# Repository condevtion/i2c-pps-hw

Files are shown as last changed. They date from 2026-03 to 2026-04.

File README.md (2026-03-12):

# Schematics for Programmable DC-DC Power Supply with I2C Interface

## About

The repository contains a schematic for the Programmable Power Supply.

## Specifications
- Controller: Texas Instruments [BQ25758S](https://www.ti.com/product/BQ25758S)
- Input voltage: 5V (4-6V - hardware power good window)
- Input current: up to 5A (hardware limited)
- Output voltage: programmable by I2C in controller defined range (3.3 - 26V)
- Output current: up to 5A (hardware limited)
- Switching frequency: 250kHz

## Schematics Structure
The device is complex enough for the schematics to be split into several pages, one for each functional block.
- Controller and Power Stage - consists of the BQ25758S controller, the power MOSFETs, and the inductor
- Input Filter and Sensor - a set of input capacitors and the input current sense resistor connected according to 4-point probes (Kelvin) method
- Output Filter and Sensor - the same for output circuit
- Master Switch - an input protection and an electronically controllable power switch
- Digital I/O and Indication - digital interface between controller and I2C host, contains as well a status LED, a power good LED, and an independent voltage regulator for the digital circuit
- Programming - a set of resistors to define controller's operating mode and HW limits for voltage and current
For now the pages contain mainly just network and hierarchical labels.

## Major Networks and Busses
- **`+5V_Prot`** - protected positive input voltage. The master switch page contains an input connector and protection circuit (fuse, TVS diode, polarity protection) after which the network starts. It is used as well to power the digital I/O and indication block
- **`+5V_Run`** - positive input voltage after the master switch itself (goes to the input filter and powers the controller). It is live while **`EN`** pin high
- **`EN`** - master switch control signal (should be high to turn the switch on and low to turn it OFF)
- **`+5V_Filtered`** - output of the input filter
- **`VOUT`** - the output voltages bus (contains power stage output and whole device output networks, goes to the output filter)
- **`I2C`** - I2C bus itself (connected to `SCL` and `SDA` pins)
- **`GPIO`** - groups digital I/O lines: interrupt, power good, status, and chip enable
- **`PROG`** - groups the rest of analog input lines which should be connected to the programming block to set operating mode and limits for the controller

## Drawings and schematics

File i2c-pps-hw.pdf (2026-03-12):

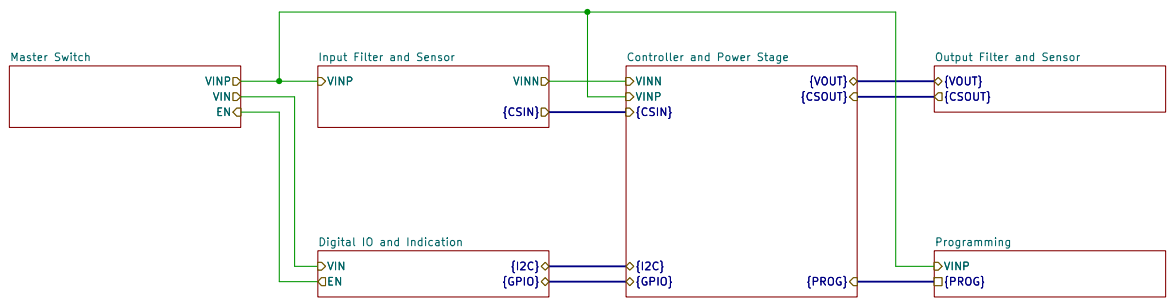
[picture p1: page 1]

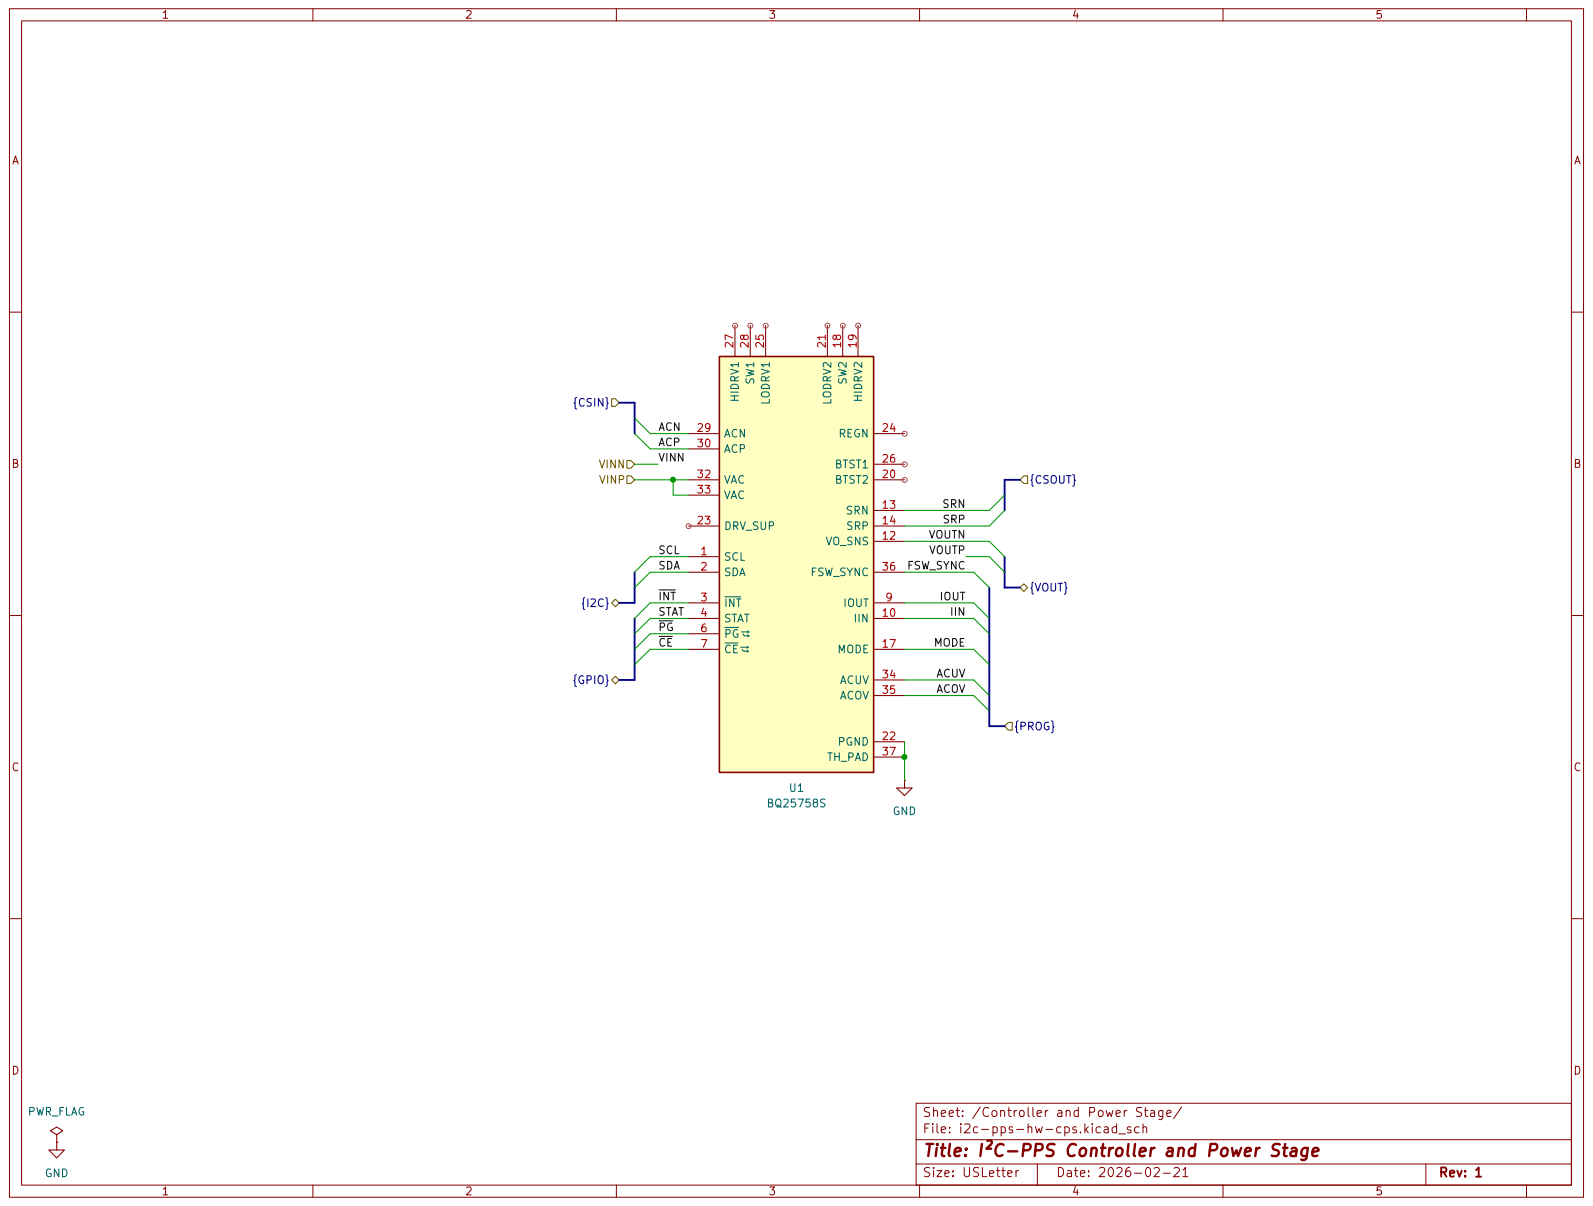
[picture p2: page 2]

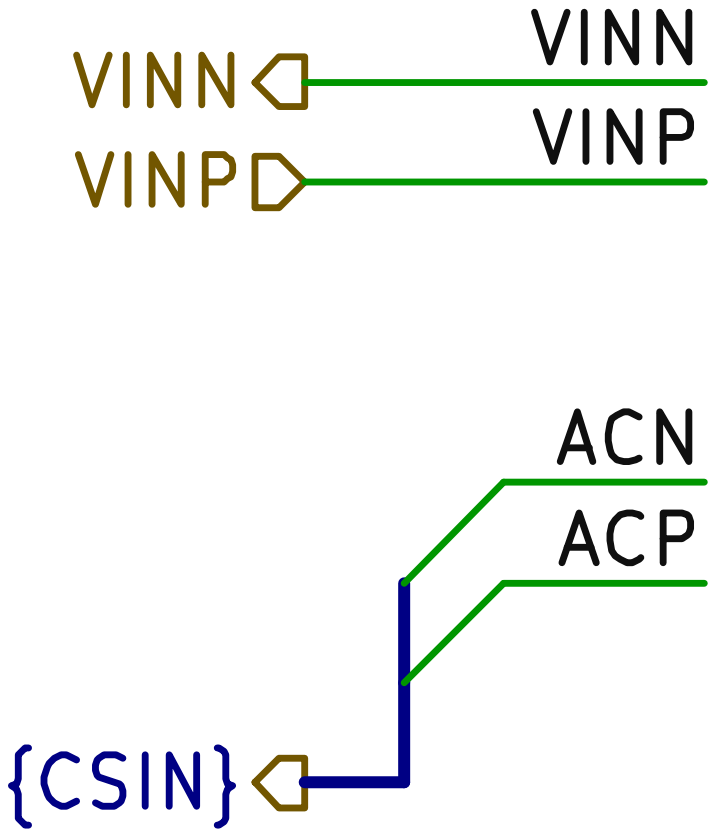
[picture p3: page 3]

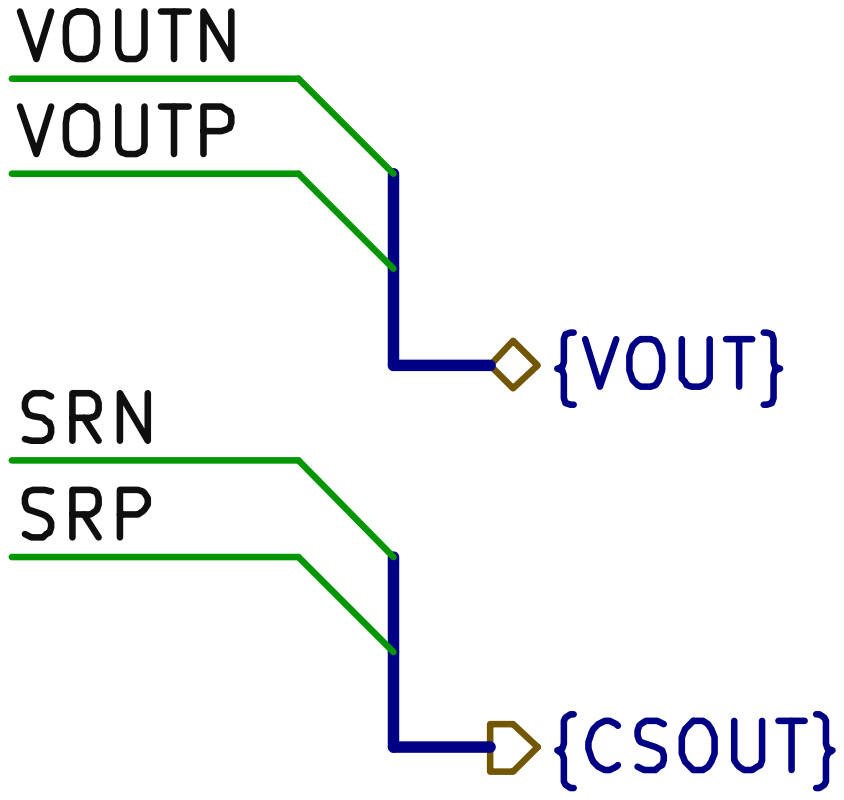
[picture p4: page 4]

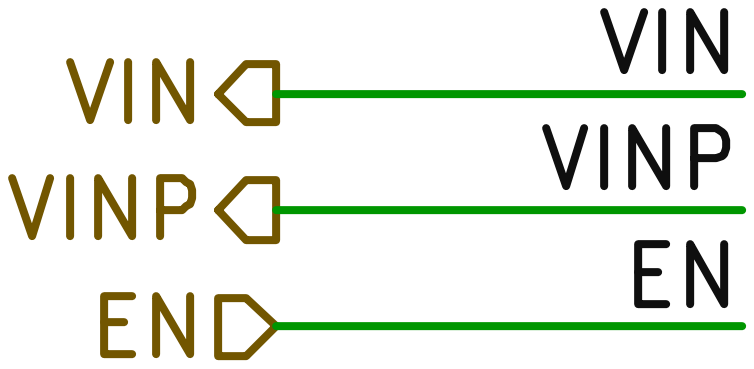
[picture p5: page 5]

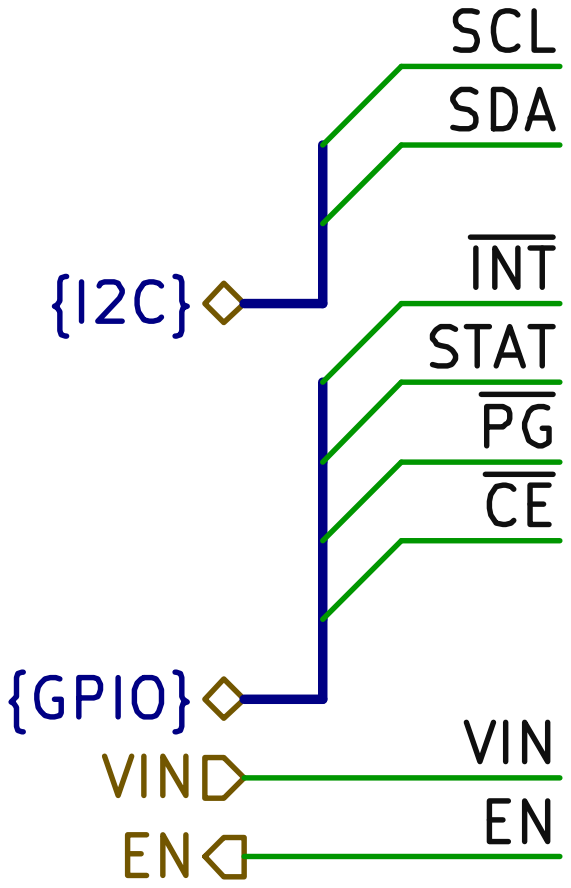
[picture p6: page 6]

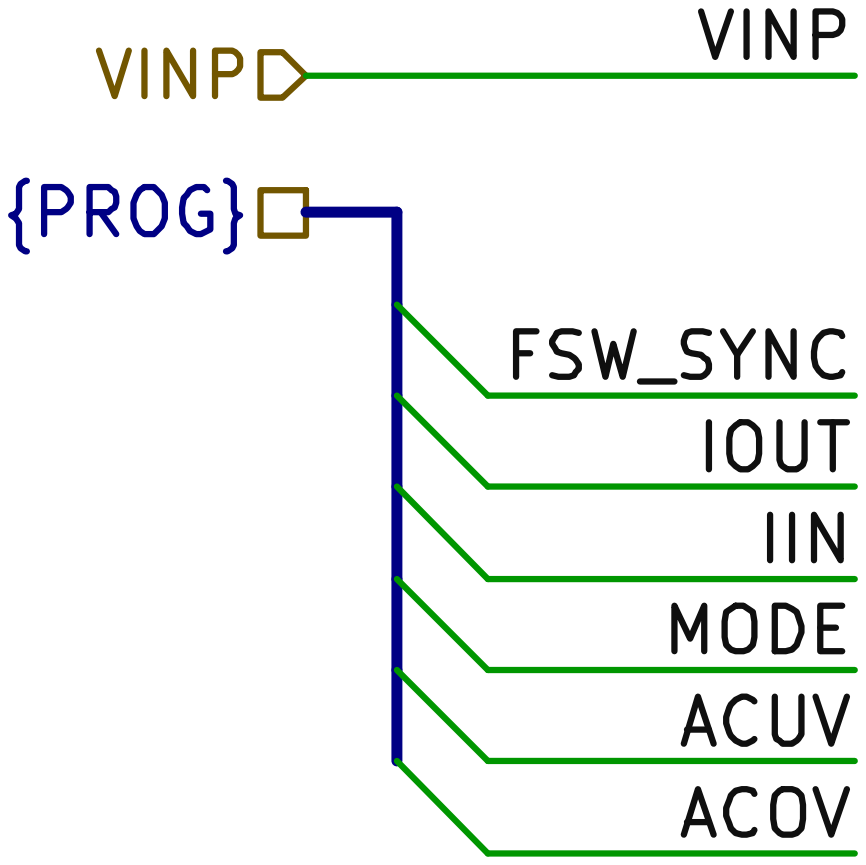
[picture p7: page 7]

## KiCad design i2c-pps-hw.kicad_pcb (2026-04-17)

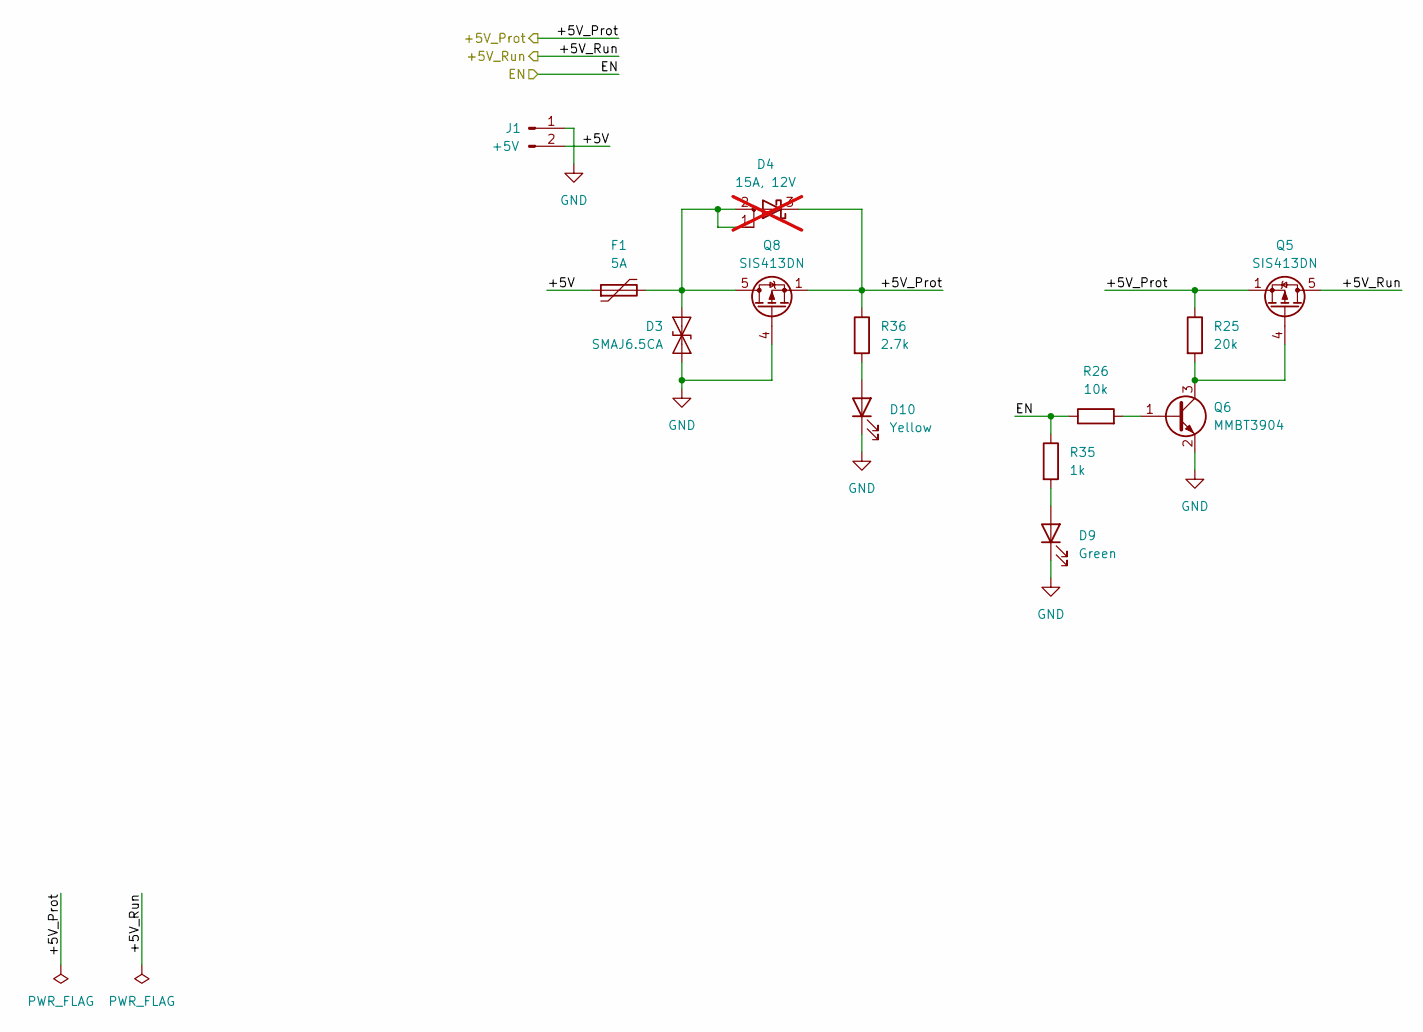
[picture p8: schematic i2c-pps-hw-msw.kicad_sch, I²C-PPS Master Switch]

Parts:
D3: SMAJ6.5CA; D_SMA; Part Number SMAJ6.5CA-AT/TR13
D4: 15A, 12V; TO-277A_ThermalVias; Part Number FSV15100V; not fitted
D9: Green; LED_0603_1608Metric_Pad1.05x0.95mm_HandSolder; Part Number LTST-C190GKT
D10: Yellow; LED_0603_1608Metric_Pad1.05x0.95mm_HandSolder; Part Number LTST-C190YKT
F1: 5A; Fuse_2920_7451Metric; Part Number SMD2920B500TF
J1: +5V; TE_1-1123724-2; Part Number 1-1123724-2
Q5, Q8: SIS413DN; Vishay_PowerPAK_1212-8_Single_ThermalVias; Part Number SIS413DN-T1-GE3
Q6: MMBT3904; SOT-23; Part Number MMBT3904-TP
R25: 20k; R_0603_1608Metric_Pad0.98x0.95mm_HandSolder; Part Number RC0603JR-0720KL
R26: 10k; R_0603_1608Metric_Pad0.98x0.95mm_HandSolder; Part Number RC0603JR-0710KL
R35: 1k; R_0603_1608Metric_Pad0.98x0.95mm_HandSolder; Part Number RC0603JR-071KL
R36: 2.7k; R_0603_1608Metric_Pad0.98x0.95mm_HandSolder; Part Number RC0603JR-072K7L

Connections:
/Controller and Power Stage/+5V_Run: Q5.5 (D); also elsewhere on the board
/Digital IO and Indication/+5V_Prot: D4.3 (K), Q5.1 (S), Q5.2 (S), Q5.3 (S), Q8.1 (S), Q8.2 (S), Q8.3 (S), R25.1, R36.1; also elsewhere on the board
/Digital IO and Indication/EN: R26.1, R35.1; also elsewhere on the board
/Master Switch/+5V: F1.1, J1.2
GND: D3.1 (A1), D9.1 (K), D10.1 (K), J1.1, Q6.2 (E), Q8.4 (G); also elsewhere on the board
unnamed: D3.2 (A2), D4.1 (A), D4.2 (A), F1.2, Q8.5 (D)
unnamed: D9.2 (A), R35.2
unnamed: D10.2 (A), R36.2
unnamed: Q5.4 (G), Q6.3 (C), R25.2
unnamed: Q6.1 (B), R26.2

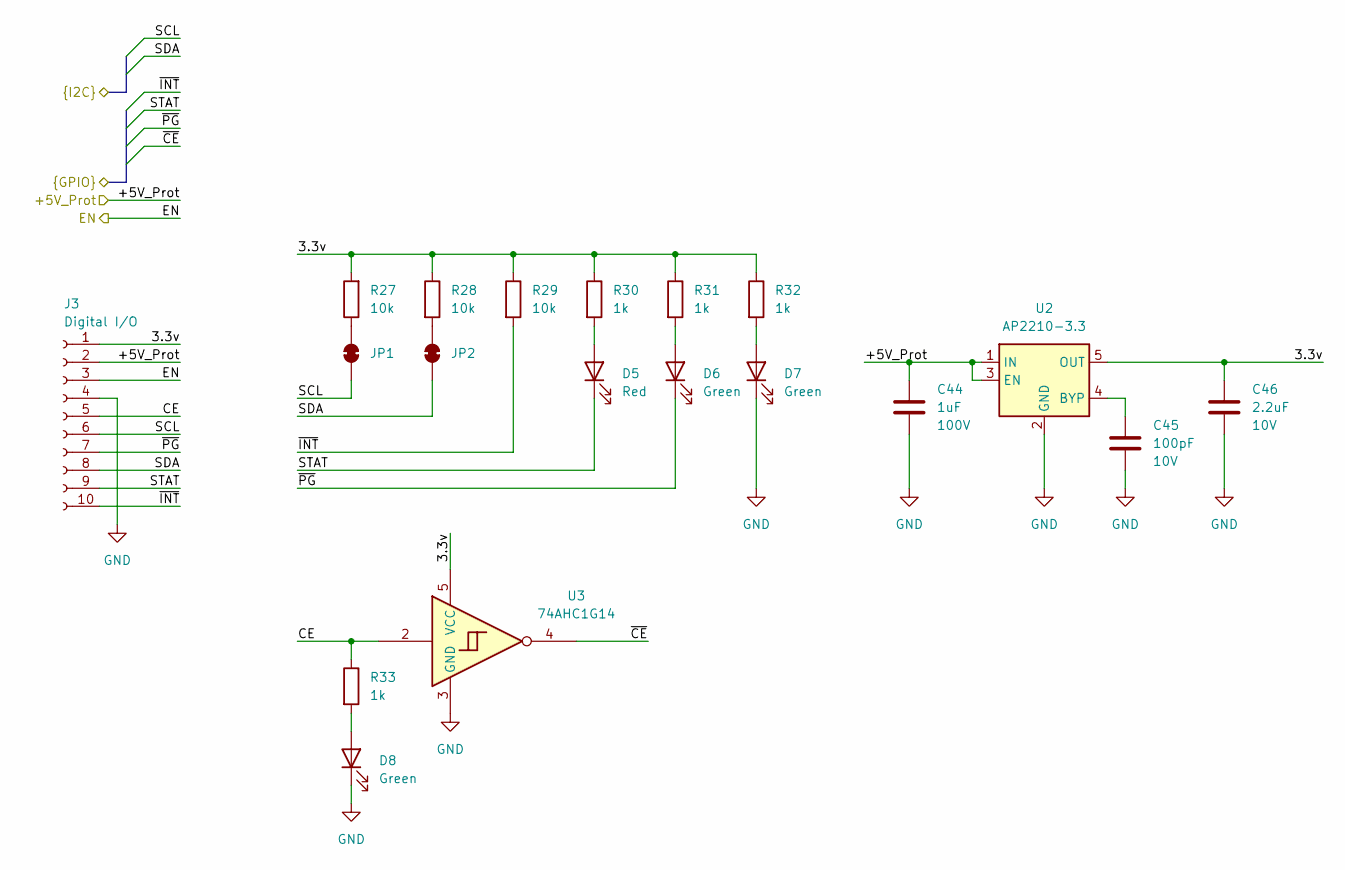
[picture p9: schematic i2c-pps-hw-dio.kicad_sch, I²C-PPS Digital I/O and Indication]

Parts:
C44: 1uF; C_0805_2012Metric; Rated Voltage 100V; Part Number 08051C105K4Z2A
C45: 100pF; C_0603_1608Metric_Pad1.08x0.95mm_HandSolder; Rated Voltage 10V; Part Number 885012206003
C46: 2.2uF; C_0603_1608Metric_Pad1.08x0.95mm_HandSolder; Rated Voltage 10V; Part Number GRM188R71A225KE15J
D5: Red; LED_0603_1608Metric_Pad1.05x0.95mm_HandSolder; Part Number LTST-C193KRKT-2A
D6, D7, D8: Green; LED_0603_1608Metric_Pad1.05x0.95mm_HandSolder; Part Number LTST-C190GKT
J3: Digital I/O; PinSocket_2x05_P2.54mm_Vertical; Part Number PPPC052LFBN-RC
JP1, JP2: SolderJumper-2_P0.65mm_Bridged_RoundedPad0.5x0.75mm
R27, R28, R29: 10k; R_0603_1608Metric_Pad0.98x0.95mm_HandSolder; Part Number RC0603JR-0710KL
R30, R31, R32, R33: 1k; R_0603_1608Metric_Pad0.98x0.95mm_HandSolder; Part Number RC0603JR-071KL
U2: AP2210-3.3; SOT-23-5; Part Number AP2210N-3.3TRG1
U3: 74AHC1G14; SOT-23-5_HandSoldering; Part Number SN74AHC1G14DBVR

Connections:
/Controller and Power Stage/SCL: J3.6, JP1.1 (A); also elsewhere on the board
/Controller and Power Stage/SDA: J3.8, JP2.1 (A); also elsewhere on the board
/Controller and Power Stage/STAT: D5.1 (K), J3.9; also elsewhere on the board
/Controller and Power Stage/~CE: U3.4; also elsewhere on the board
/Controller and Power Stage/~INT: J3.10, R29.2; also elsewhere on the board
/Controller and Power Stage/~PG: D6.1 (K), J3.7; also elsewhere on the board
/Digital IO and Indication/3.3v: C46.1, J3.1, R27.2, R28.1, R29.1, R30.1, R31.1, R32.1, U2.5 (OUT), U3.5 (VCC)
/Digital IO and Indication/+5V_Prot: C44.1, J3.2, U2.1 (IN), U2.3 (EN); also elsewhere on the board
/Digital IO and Indication/CE: J3.5, R33.1, U3.2
/Digital IO and Indication/EN: J3.3; also elsewhere on the board
GND: C44.2, C45.2, C46.2, D7.1 (K), D8.1 (K), J3.4, U2.2 (GND), U3.3 (GND); also elsewhere on the board
unnamed: D5.2 (A), R30.2
unnamed: D6.2 (A), R31.2
unnamed: D7.2 (A), R32.2
unnamed: D8.2 (A), R33.2
unnamed: JP1.2 (B), R27.1
unnamed: JP2.2 (B), R28.2
unnamed: C45.1, U2.4 (BYP)

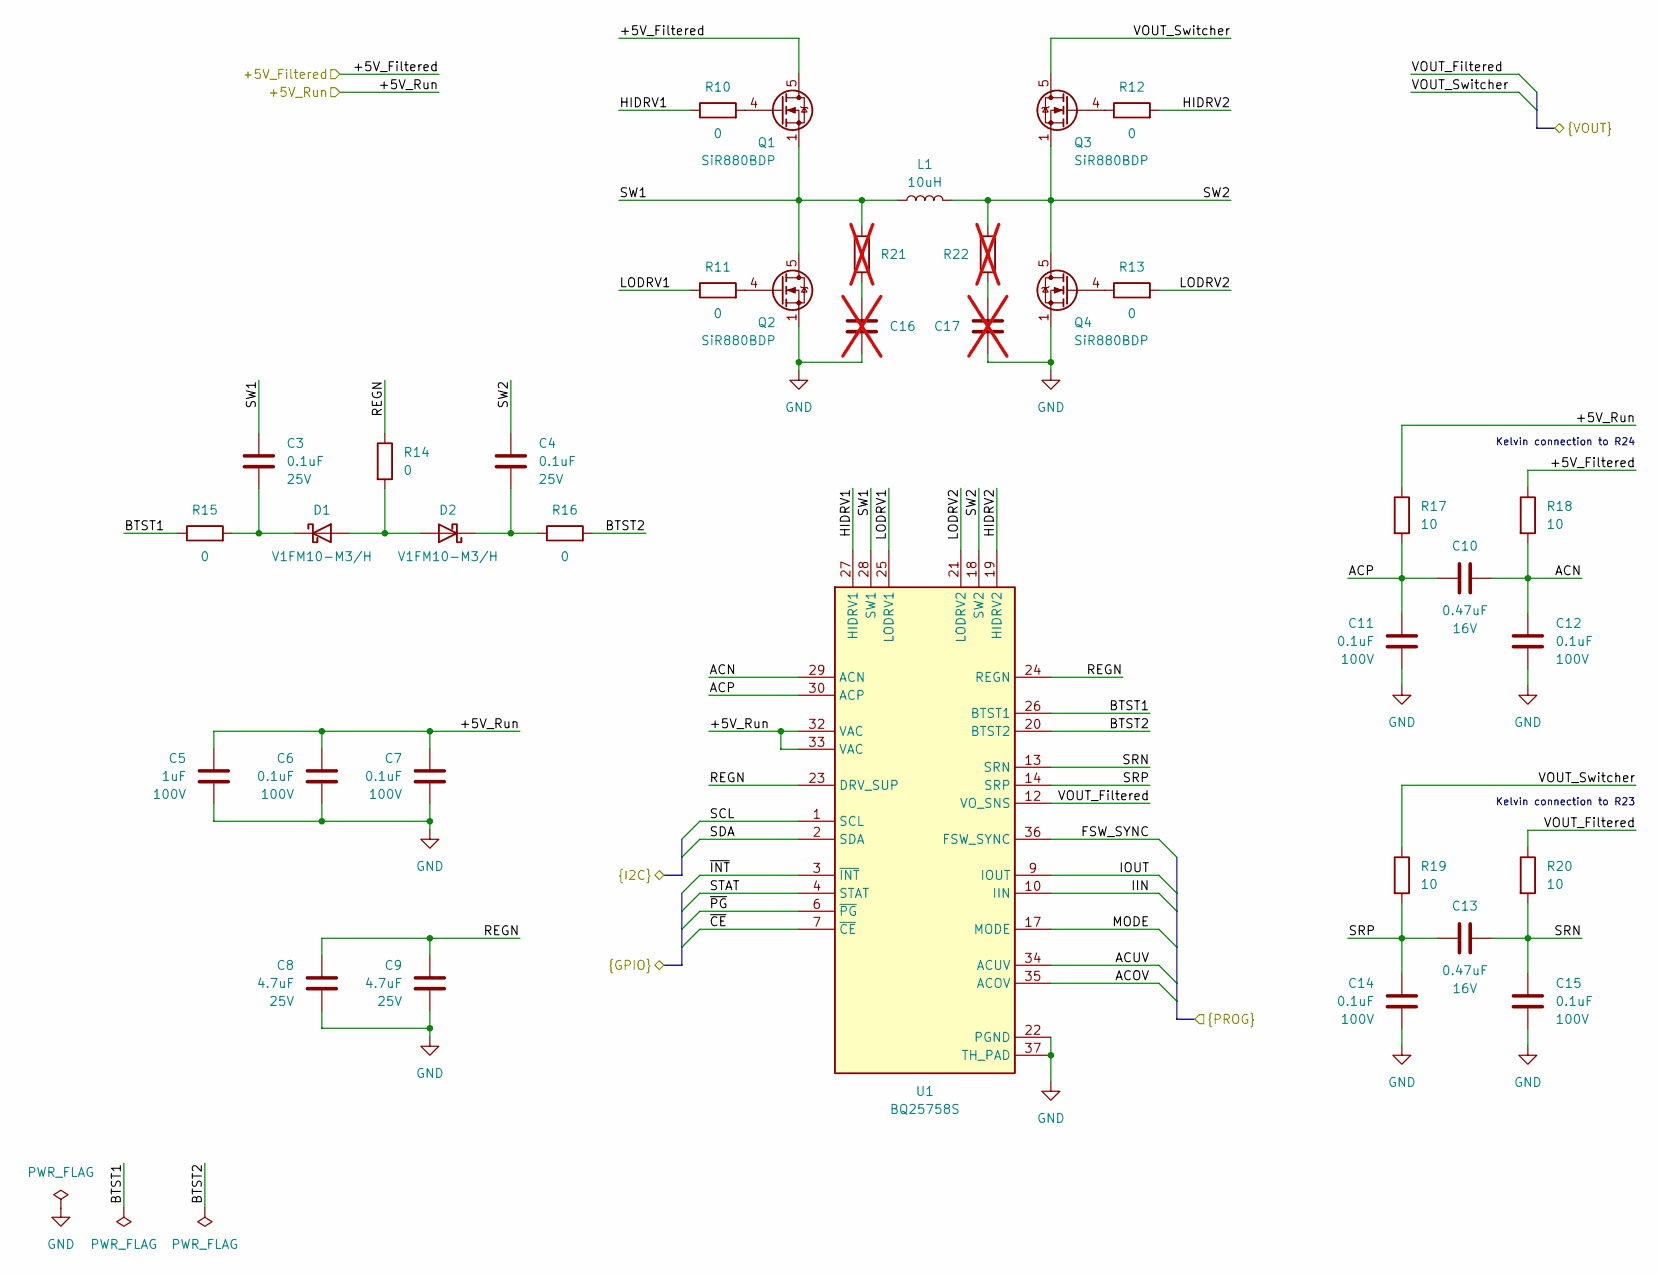
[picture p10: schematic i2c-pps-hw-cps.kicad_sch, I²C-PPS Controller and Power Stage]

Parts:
C3, C4: 0.1uF; C_0603_1608Metric_Pad1.08x0.95mm_HandSolder; Rated Voltage 25V; Part Number C0603C104K3RACTU
C5: 1uF; C_0805_2012Metric; Rated Voltage 100V; Part Number 08051C105K4Z2A
C6, C7, C11, C12, C14, C15: 0.1uF; C_0603_1608Metric_Pad1.08x0.95mm_HandSolder; Rated Voltage 100V; Part Number HMK107B7104KAHT
C8, C9: 4.7uF; C_0805_2012Metric; Rated Voltage 25V; Part Number CGA4J1X7R1E475K125AE
C10, C13: 0.47uF; C_0603_1608Metric_Pad1.08x0.95mm_HandSolder; Rated Voltage 16V; Part Number CL10B474KO8NNNC
C16, C17: C_0805_2012Metric; not fitted
D1, D2: V1FM10-M3/H; D_SMF; Part Number V1FM10-M3/H
L1: 10uH; L_Bourns_SRP1038A_10.0x11.0mm; Part Number SRP1038A-100M
Q1, Q2, Q3, Q4: SiR880BDP; PowerPAK_SO-8_Single_ThermalVias; Part Number SIR880BDP-T1-RE3
R10, R11, R12, R13, R15, R16: 0; R_0603_1608Metric_Pad0.98x0.95mm_HandSolder; Part Number RC0603JR-070RL
R14: 0; R_0805_2012Metric; Part Number CRCW08050000Z0EAC
R17, R18, R19, R20: 10; R_0603_1608Metric_Pad0.98x0.95mm_HandSolder; Part Number RC0603FR-0710RL
R21, R22: R_1210_3225Metric; not fitted
U1: BQ25758S; Texas_RRV0036A_VQFN-36-1EP_4.8x5.8mm_P0.5mm_EP3.6x4.6mm_The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; Part Number BQ25758SRRVR

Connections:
/Controller and Power Stage/+5V_Filtered: Q1.5 (D), R18.1; also elsewhere on the board
/Controller and Power Stage/+5V_Run: C5.1, C6.1, C7.1, R17.1, U1.32 (VAC), U1.33 (VAC); also elsewhere on the board
/Controller and Power Stage/ACN: C10.1, C12.1, R18.2, U1.29 (ACN)
/Controller and Power Stage/ACOV: U1.35 (ACOV); also elsewhere on the board
/Controller and Power Stage/ACP: C10.2, C11.1, R17.2, U1.30 (ACP)
/Controller and Power Stage/ACUV: U1.34 (ACUV); also elsewhere on the board
/Controller and Power Stage/BTST1: R15.1, U1.26 (BTST1)
/Controller and Power Stage/BTST2: R16.2, U1.20 (BTST2)
/Controller and Power Stage/FSW_SYNC: U1.36 (FSW_SYNC); also elsewhere on the board
/Controller and Power Stage/HIDRV1: R10.1, U1.27 (HIDRV1)
/Controller and Power Stage/HIDRV2: R12.2, U1.19 (HIDRV2)
/Controller and Power Stage/IIN: U1.10 (IIN); also elsewhere on the board
/Controller and Power Stage/IOUT: U1.9 (IOUT); also elsewhere on the board
/Controller and Power Stage/LODRV1: R11.1, U1.25 (LODRV1)
/Controller and Power Stage/LODRV2: R13.2, U1.21 (LODRV2)
/Controller and Power Stage/MODE: U1.17 (MODE); also elsewhere on the board
/Controller and Power Stage/REGN: C8.1, C9.1, R14.1, U1.23 (DRV_SUP), U1.24 (REGN)
/Controller and Power Stage/SCL: U1.1 (SCL); also elsewhere on the board
/Controller and Power Stage/SDA: U1.2 (SDA); also elsewhere on the board
/Controller and Power Stage/SRN: C13.1, C15.1, R20.2, U1.13 (SRN)
/Controller and Power Stage/SRP: C13.2, C14.1, R19.2, U1.14 (SRP)
/Controller and Power Stage/STAT: U1.4 (STAT); also elsewhere on the board
/Controller and Power Stage/SW1: C3.1, L1.1, Q1.1 (S), Q1.2 (S), Q1.3 (S), Q2.5 (D), R21.1, U1.28 (SW1)
/Controller and Power Stage/SW2: C4.1, L1.2, Q3.1 (S), Q3.2 (S), Q3.3 (S), Q4.5 (D), R22.1, U1.18 (SW2)
/Controller and Power Stage/VOUT_Filtered: R20.1, U1.12 (VO_SNS); also elsewhere on the board
/Controller and Power Stage/VOUT_Switcher: Q3.5 (D), R19.1; also elsewhere on the board
/Controller and Power Stage/~CE: U1.7 (~CE); also elsewhere on the board
/Controller and Power Stage/~INT: U1.3 (~INT); also elsewhere on the board
/Controller and Power Stage/~PG: U1.6 (~PG); also elsewhere on the board
GND: C5.2, C6.2, C7.2, C8.2, C9.2, C11.2, C12.2, C14.2, C15.2, C16.2, C17.2, Q2.1 (S), Q2.2 (S), Q2.3 (S), Q4.1 (S), Q4.2 (S), Q4.3 (S), U1.22 (PGND), U1.37 (TH_PAD); also elsewhere on the board
unnamed: C16.1, R21.2
unnamed: C17.1, R22.2
unnamed: D1.2 (A), D2.2 (A), R14.2
unnamed: C3.2, D1.1 (K), R15.2
unnamed: C4.2, D2.1 (K), R16.1
unnamed: Q1.4 (G), R10.2
unnamed: Q2.4 (G), R11.2
unnamed: Q3.4 (G), R12.1
unnamed: Q4.4 (G), R13.1

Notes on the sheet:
Kelvin connection to R24
Kelvin connection to R23

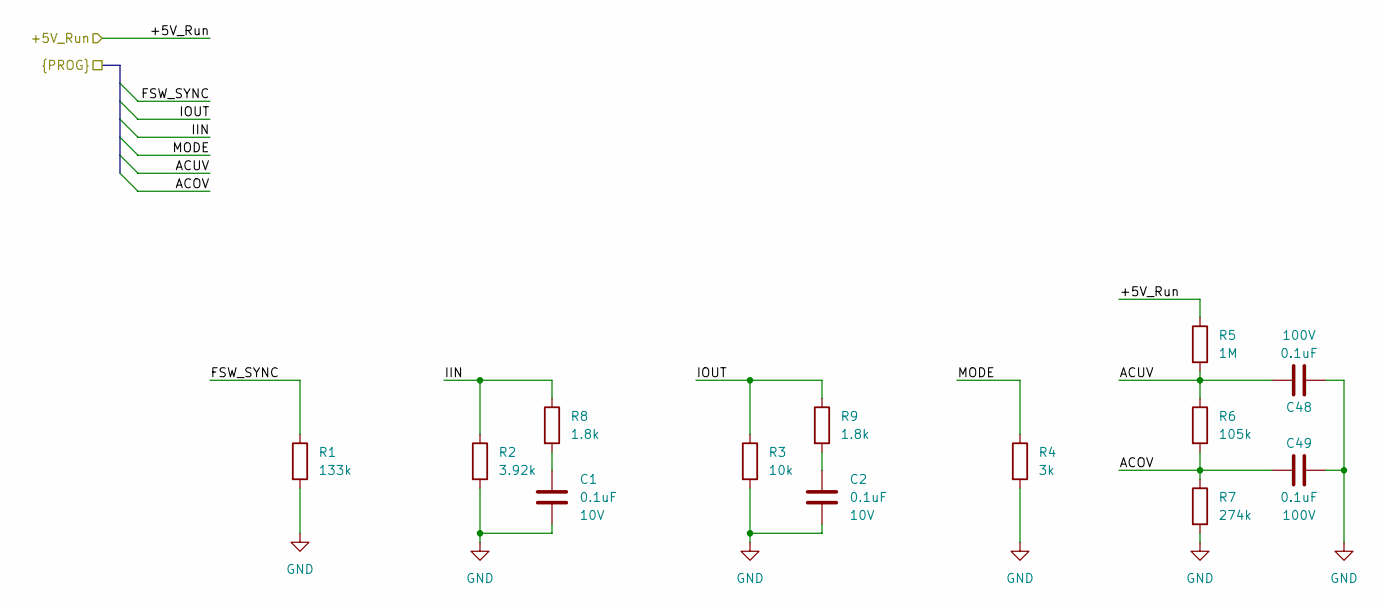
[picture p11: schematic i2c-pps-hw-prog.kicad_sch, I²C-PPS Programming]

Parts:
C1, C2: 0.1uF; C_0603_1608Metric_Pad1.08x0.95mm_HandSolder; Rated Voltage 10V; Part Number C0603C104K8RACTU
C48, C49: 0.1uF; C_0603_1608Metric_Pad1.08x0.95mm_HandSolder; Rated Voltage 100V; Part Number HMK107B7104KAHT
R1: 133k; R_0603_1608Metric_Pad0.98x0.95mm_HandSolder; Part Number RC0603FR-07133KL
R2: 3.92k; R_0603_1608Metric_Pad0.98x0.95mm_HandSolder; Part Number RC0603FR-073K92L
R3: 10k; R_0603_1608Metric_Pad0.98x0.95mm_HandSolder; Part Number RC0603FR-0710KL
R4: 3k; R_0603_1608Metric_Pad0.98x0.95mm_HandSolder; Part Number RC0603FR-073KL
R5: 1M; R_0805_2012Metric; Part Number ERA-6AEB105V
R6: 105k; R_0805_2012Metric; Part Number ERA-6AEB1053V
R7: 274k; R_0805_2012Metric; Part Number ERA-6AEB2743V
R8, R9: 1.8k; R_0603_1608Metric_Pad0.98x0.95mm_HandSolder; Part Number RC0603JR-071K8L

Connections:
/Controller and Power Stage/+5V_Run: R5.1; also elsewhere on the board
/Controller and Power Stage/ACOV: C49.1, R6.2, R7.1; also elsewhere on the board
/Controller and Power Stage/ACUV: C48.1, R5.2, R6.1; also elsewhere on the board
/Controller and Power Stage/FSW_SYNC: R1.1; also elsewhere on the board
/Controller and Power Stage/IIN: R2.1, R8.1; also elsewhere on the board
/Controller and Power Stage/IOUT: R3.1, R9.1; also elsewhere on the board
/Controller and Power Stage/MODE: R4.1; also elsewhere on the board
GND: C1.2, C2.2, C48.2, C49.2, R1.2, R2.2, R3.2, R4.2, R7.2; also elsewhere on the board
unnamed: C1.1, R8.2
unnamed: C2.1, R9.2

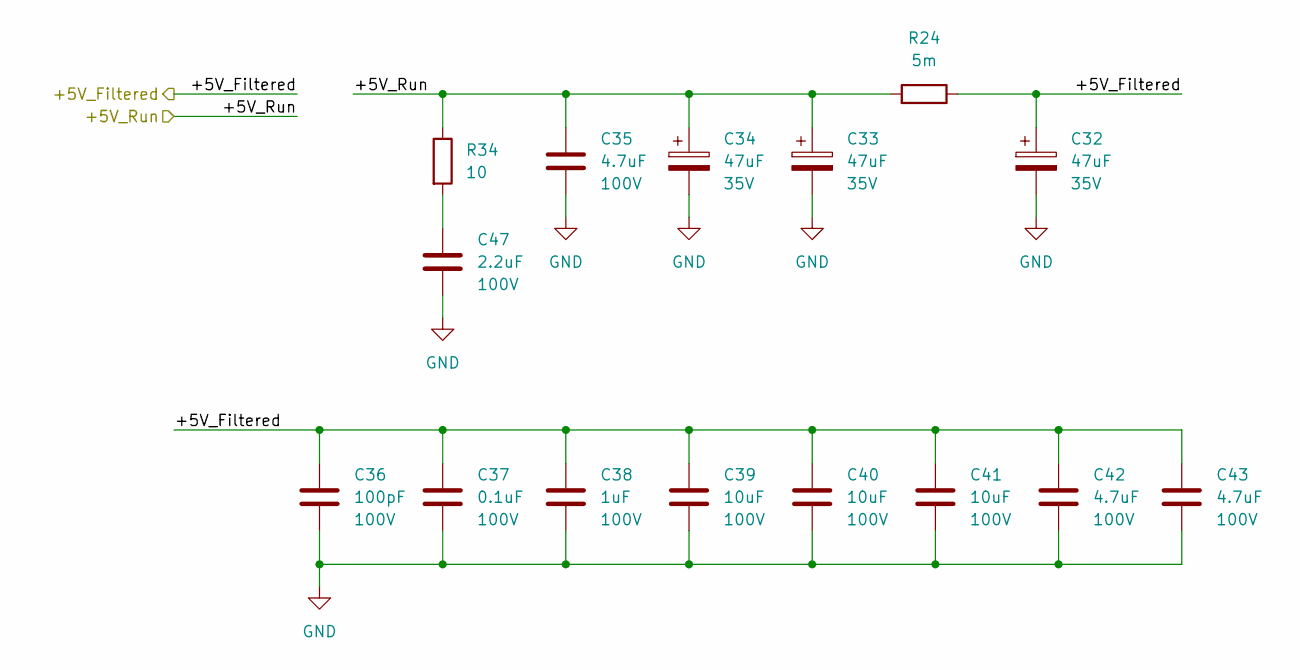
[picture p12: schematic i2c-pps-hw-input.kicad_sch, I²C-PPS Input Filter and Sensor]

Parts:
C32, C33, C34: 47uF; CP_Elec_6.3x5.7; Rated Voltage 35V; Part Number A768EB476M1VLAE042
C35, C42, C43: 4.7uF; C_1210_3225Metric; Rated Voltage 100V; Part Number GCJ32DC72A475KE01L
C36: 100pF; C_0603_1608Metric_Pad1.08x0.95mm_HandSolder; Rated Voltage 100V; Part Number CGA3E2C0G2A101J080AA
C37: 0.1uF; C_0603_1608Metric_Pad1.08x0.95mm_HandSolder; Rated Voltage 100V; Part Number HMK107B7104KAHT
C38: 1uF; C_0805_2012Metric; Rated Voltage 100V; Part Number 08051C105K4Z2A
C39, C40, C41: 10uF; C_1210_3225Metric; Rated Voltage 100V; Part Number C3225X7R2A106K250AC
C47: 2.2uF; C_1210_3225Metric; Rated Voltage 100V; Part Number CGA6N3X7R2A225K230AE
R24: 5m; R_2512_6332Metric; Part Number PA2512FKM070R005E
R34: 10; R_1206_3216Metric; Part Number SR1206FR-7T10RL

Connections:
/Controller and Power Stage/+5V_Filtered: C32.1, C36.1, C37.1, C38.1, C39.1, C40.1, C41.1, C42.1, C43.1, R24.1; also elsewhere on the board
/Controller and Power Stage/+5V_Run: C33.1, C34.1, C35.1, R24.2, R34.1; also elsewhere on the board
GND: C32.2, C33.2, C34.2, C35.2, C36.2, C37.2, C38.2, C39.2, C40.2, C41.2, C42.2, C43.2, C47.2; also elsewhere on the board
unnamed: C47.1, R34.2

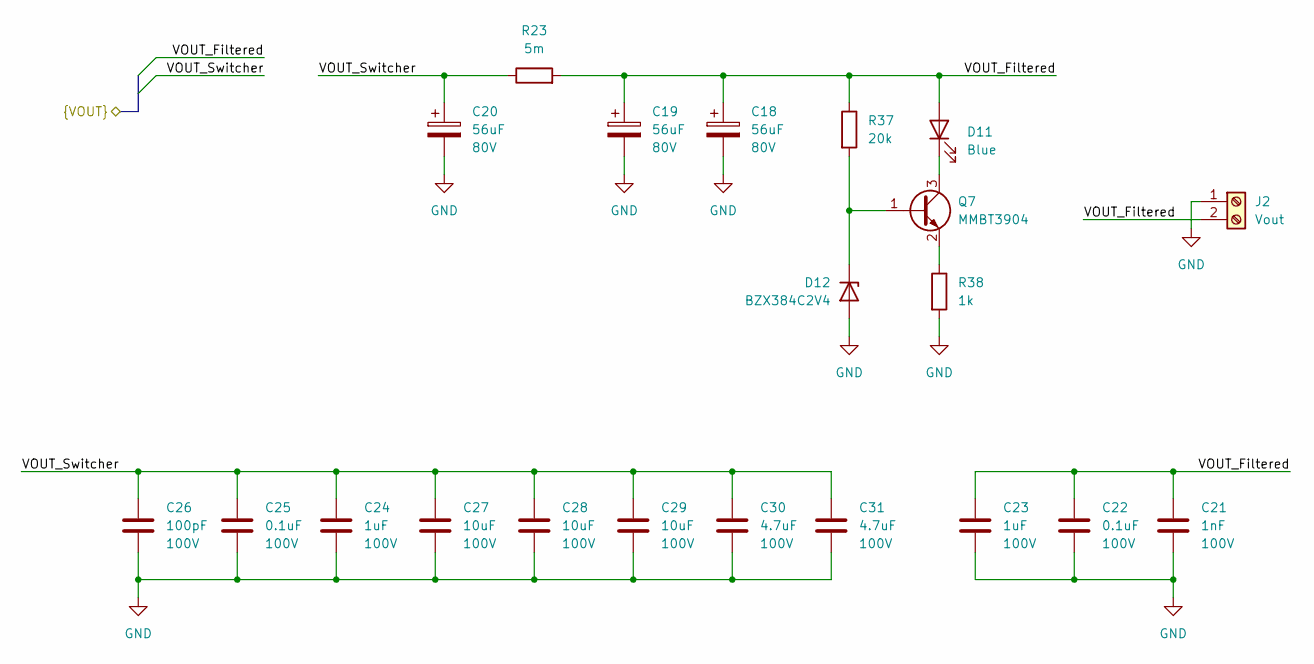
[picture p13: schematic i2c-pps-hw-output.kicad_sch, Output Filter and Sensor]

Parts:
C18, C19, C20: 56uF; C_Elec_10x10.2; Rated Voltage 80V; Part Number A768MS566M1KLAE034
C21: 1nF; C_0603_1608Metric_Pad1.08x0.95mm_HandSolder; Rated Voltage 100V; Part Number CGA3E2X7R2A102K080AA
C22, C25: 0.1uF; C_0603_1608Metric_Pad1.08x0.95mm_HandSolder; Rated Voltage 100V; Part Number HMK107B7104KAHT
C23, C24: 1uF; C_0805_2012Metric; Rated Voltage 100V; Part Number 08051C105K4Z2A
C26: 100pF; C_0603_1608Metric_Pad1.08x0.95mm_HandSolder; Rated Voltage 100V; Part Number CGA3E2C0G2A101J080AA
C27, C28, C29: 10uF; C_1210_3225Metric; Rated Voltage 100V; Part Number C3225X7R2A106K250AC
C30, C31: 4.7uF; C_1210_3225Metric; Rated Voltage 100V; Part Number GCJ32DC72A475KE01L
D11: Blue; LED_0603_1608Metric_Pad1.05x0.95mm_HandSolder; Part Number LTST-C193TBKT-5A
D12: BZX384C2V4; D_SOD-323; Part Number BZX384C2V4-E3-08
J2: Vout; TerminalBlock_MetzConnect_Type101_RT01602HBWC_1x02_P5.08mm_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; Part Number TB006-508-02BE
Q7: MMBT3904; SOT-23; Part Number MMBT3904-TP
R23: 5m; R_2512_6332Metric; Part Number PA2512FKM070R005E
R37: 20k; R_0603_1608Metric_Pad0.98x0.95mm_HandSolder; Part Number RC0603JR-0720KL
R38: 1k; R_0603_1608Metric_Pad0.98x0.95mm_HandSolder; Part Number RC0603JR-071KL

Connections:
/Controller and Power Stage/VOUT_Filtered: C18.1, C19.1, C21.1, C22.1, C23.1, D11.2 (A), J2.2, R23.2, R37.1; also elsewhere on the board
/Controller and Power Stage/VOUT_Switcher: C20.1, C24.1, C25.1, C26.1, C27.1, C28.1, C29.1, C30.1, C31.1, R23.1; also elsewhere on the board
GND: C18.2, C19.2, C20.2, C21.2, C22.2, C23.2, C24.2, C25.2, C26.2, C27.2, C28.2, C29.2, C30.2, C31.2, D12.2 (A), J2.1, R38.2; also elsewhere on the board
unnamed: D11.1 (K), Q7.3 (C)
unnamed: D12.1 (K), Q7.1 (B), R37.2
unnamed: Q7.2 (E), R38.1

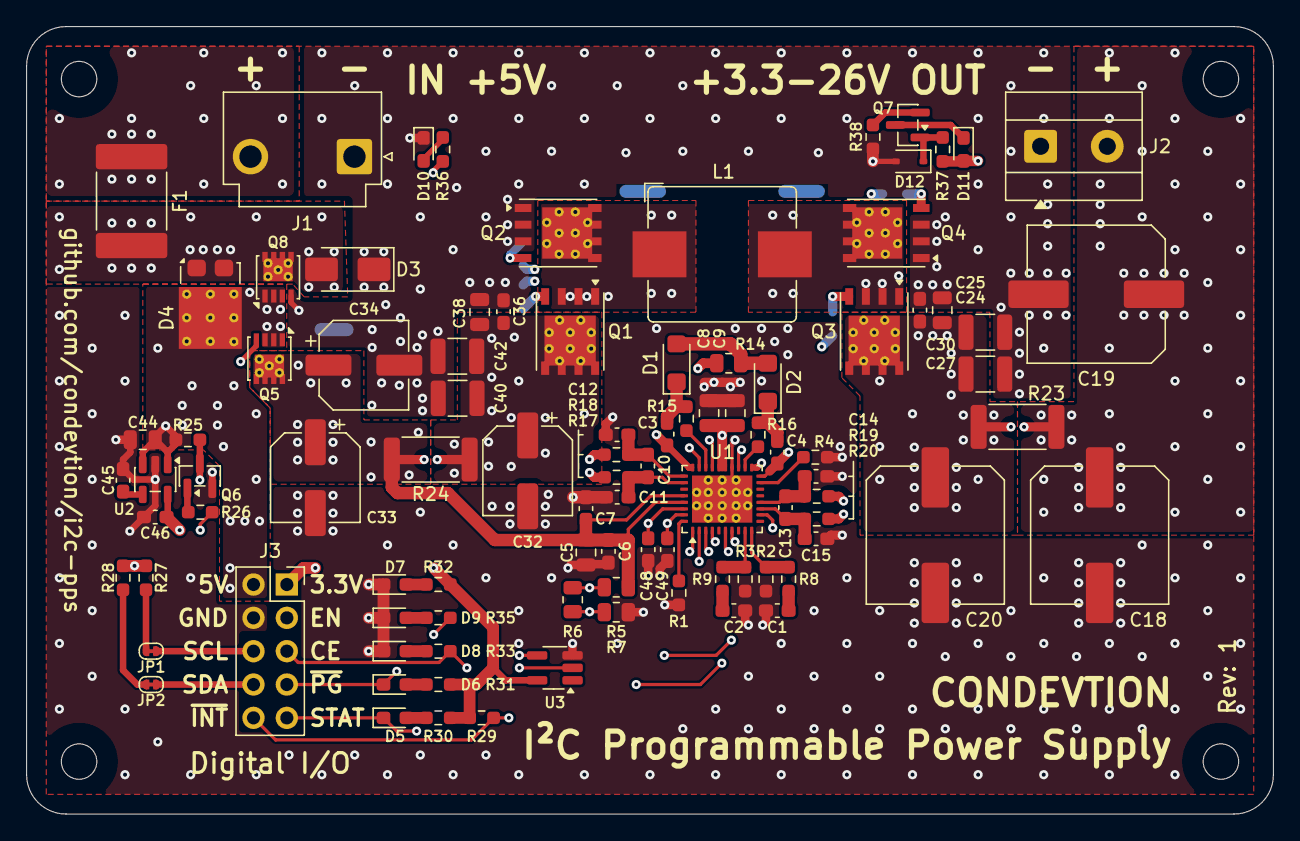
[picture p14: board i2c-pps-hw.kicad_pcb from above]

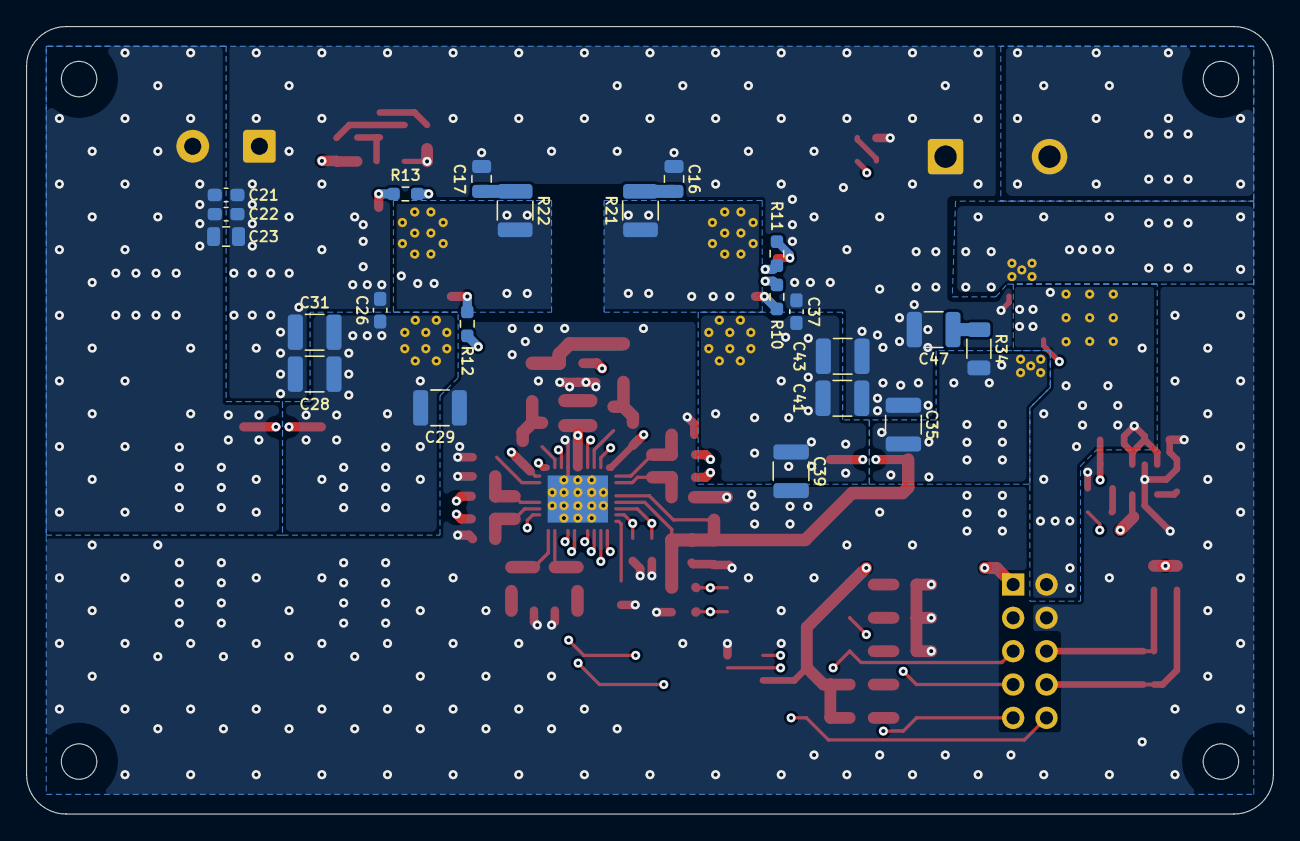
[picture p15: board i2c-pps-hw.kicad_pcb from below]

Board: 4 copper layers, 95.0 x 60.0 mm, 121 parts (22 on the bottom side), 62 nets.

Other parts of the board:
MH1, MH2, MH3, MH4: MountingHole_2.7mm_M2.5_Guarded

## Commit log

2026-02-19 Create initial version of the schematics
    [i2c-pps-hw.kicad_pcb, i2c-pps-hw.kicad_sch]
2026-03-12 Add symbol and footprints for the BQ25758S controller
2026-03-12 Create a page per devices block and connect them
    [i2c-pps-hw-cps.kicad_sch, i2c-pps-hw-dio.kicad_sch, i2c-pps-hw-input.kicad_sch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]
2026-03-12 Design schematics and set per component requirements
    [i2c-pps-hw-cps.kicad_sch, i2c-pps-hw-dio.kicad_sch, i2c-pps-hw-input.kicad_sch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]
2026-03-12 Rename VIN to +5V_Prot for clarity
    [i2c-pps-hw-dio.kicad_sch, i2c-pps-hw-msw_sch.kicad_sch, i2c-pps-hw.kicad_sch]
2026-03-12 Rename VINP to +5V_Run for clarity
    [i2c-pps-hw-cps.kicad_sch, i2c-pps-hw-input.kicad_sch, i2c-pps-hw-msw_sch.kicad_sch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]
2026-03-12 Rename VINN to +5V_Filtered for clarity
    [i2c-pps-hw-cps.kicad_sch, i2c-pps-hw-input.kicad_sch, i2c-pps-hw.kicad_sch]
2026-03-12 Rename VOUTP to VOUT_Switcher for clarity
    [i2c-pps-hw-cps.kicad_sch, i2c-pps-hw-output.kicad_sch]
2026-03-12 Rename VOUTN to VOUT_Filtered for clarity
    [i2c-pps-hw-cps.kicad_sch, i2c-pps-hw-output.kicad_sch]
2026-03-12 Remove alias CSIN as the bus has been removed
    [i2c-pps-hw-cps.kicad_sch]
2026-03-12 Remove CSIN and CSOUT busses from readme as they have been deleted from schematics
2026-03-12 Add more indicator LEDs
    [i2c-pps-hw-dio.kicad_sch, i2c-pps-hw-input.kicad_sch, i2c-pps-hw-msw_sch.kicad_sch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]
2026-03-12 Switch to MOSFET based polarity protection
    [i2c-pps-hw-msw_sch.kicad_sch]
2026-03-12 Fix errors and warnings reported by ERC
    [i2c-pps-hw-cps.kicad_sch, i2c-pps-hw-dio.kicad_sch, i2c-pps-hw-msw_sch.kicad_sch]
2026-03-12 Select market available components
    [i2c-pps-hw-cps.kicad_sch, i2c-pps-hw-dio.kicad_sch, i2c-pps-hw-input.kicad_sch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]
2026-03-12 Create an empty PCB with RPi5/Z2 dimensions
    [i2c-pps-hw.kicad_pcb]
2026-03-12 Setup the board and move components from schematics
    [i2c-pps-hw-msw.kicad_sch, i2c-pps-hw.kicad_pcb]
2026-03-13 Add PCBWay custom design rules, adjust board constraints, and physical stackup for 4-layers 2/1.5oz copper
    [i2c-pps-hw.kicad_pcb]
2026-03-15 Adjust design rules and footprints to fit each other
    [i2c-pps-hw.kicad_pcb]
2026-03-15 Route driving part of the power stage
    [i2c-pps-hw.kicad_pcb]
2026-03-17 Place and route controller surroundings
    [i2c-pps-hw-prog.kicad_sch, i2c-pps-hw.kicad_pcb]
2026-03-19 Place and route power stage
    [i2c-pps-hw.kicad_pcb]
2026-03-19 Add thermal vias to the power stage transistors
    [i2c-pps-hw-cps.kicad_sch, i2c-pps-hw.kicad_pcb]
2026-03-19 Remove mounting and resize board
    [i2c-pps-hw.kicad_pcb]
2026-03-24 Implement approximate component placement
    [i2c-pps-hw-dio.kicad_sch, i2c-pps-hw-msw.kicad_sch, i2c-pps-hw.kicad_pcb]
2026-03-24 Add thermal vias to the master switch components
    [i2c-pps-hw-msw.kicad_sch, i2c-pps-hw.kicad_pcb]
2026-04-07 Route the PCB
    [i2c-pps-hw-dio.kicad_sch, i2c-pps-hw-output.kicad_sch, i2c-pps-hw.kicad_pcb]
2026-04-07 Add manufacturer and part number to Vout terminal
    [i2c-pps-hw-output.kicad_sch]
2026-04-10 Add more vias
    [i2c-pps-hw.kicad_pcb]
2026-04-17 Adjust vias, GND top zone, and setup fabrication output
    [i2c-pps-hw.kicad_pcb]
